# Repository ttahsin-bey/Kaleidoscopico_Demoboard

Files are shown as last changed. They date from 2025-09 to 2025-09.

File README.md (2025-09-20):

# Demoboard for LFT's Demo "Kaleidoscopico"

Demos always look better on real hardware. That's what everyone says.

That's why I designed this small circuit board for myself, so that I can run LFT's demo on real hardware instead of just watching it on YouTube. I didn't want to build his version on a stripboard, but preferred a clean solution with SMT components.

Rendering

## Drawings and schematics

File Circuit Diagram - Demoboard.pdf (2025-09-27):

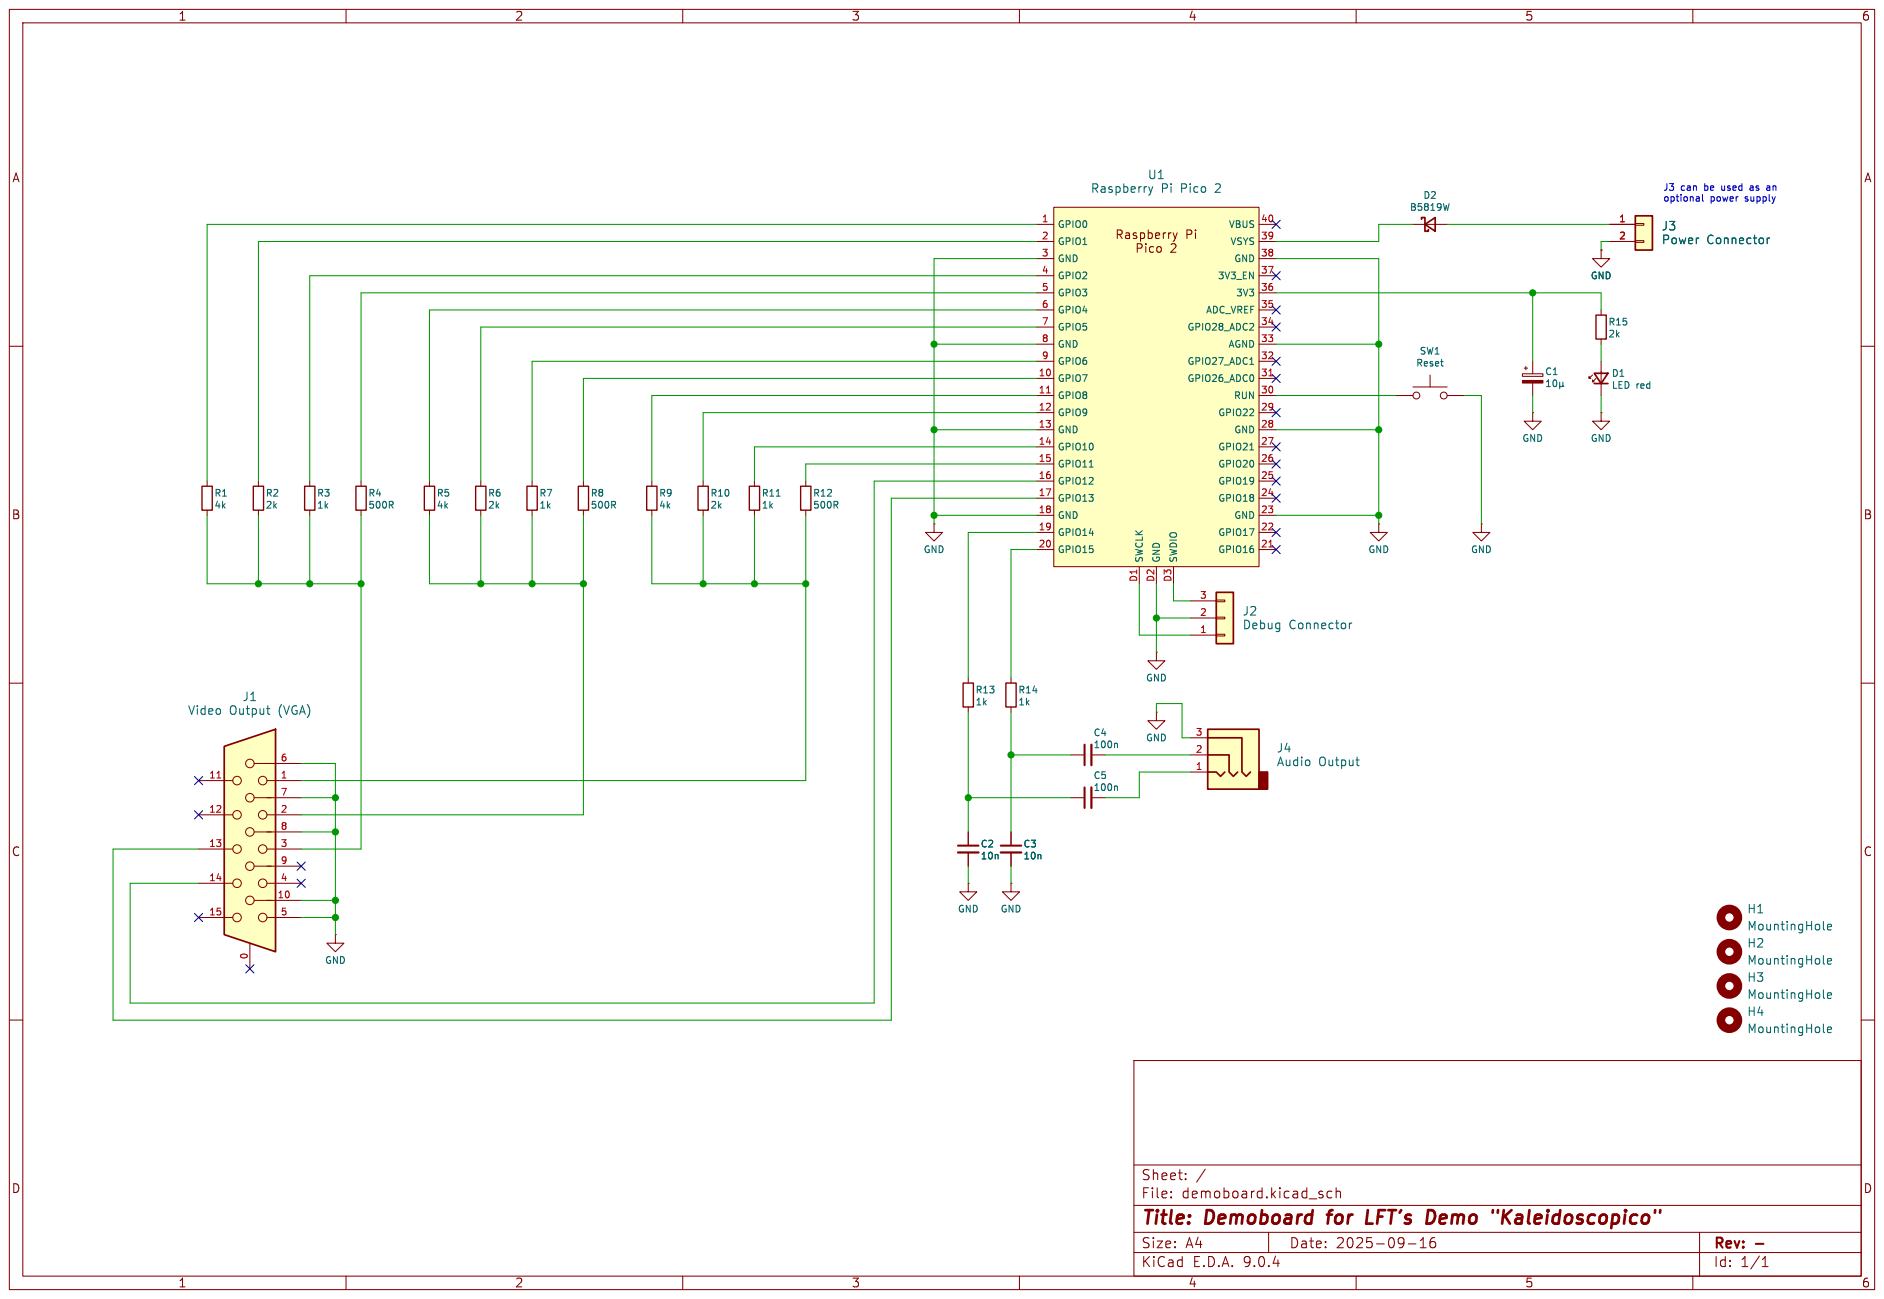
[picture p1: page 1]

J3 can be used as an

File: demoboard.kicad_sch Sheet: /
Id: 1/1 Title: Demoboard for LFT's Demo "Kaleidoscopico"

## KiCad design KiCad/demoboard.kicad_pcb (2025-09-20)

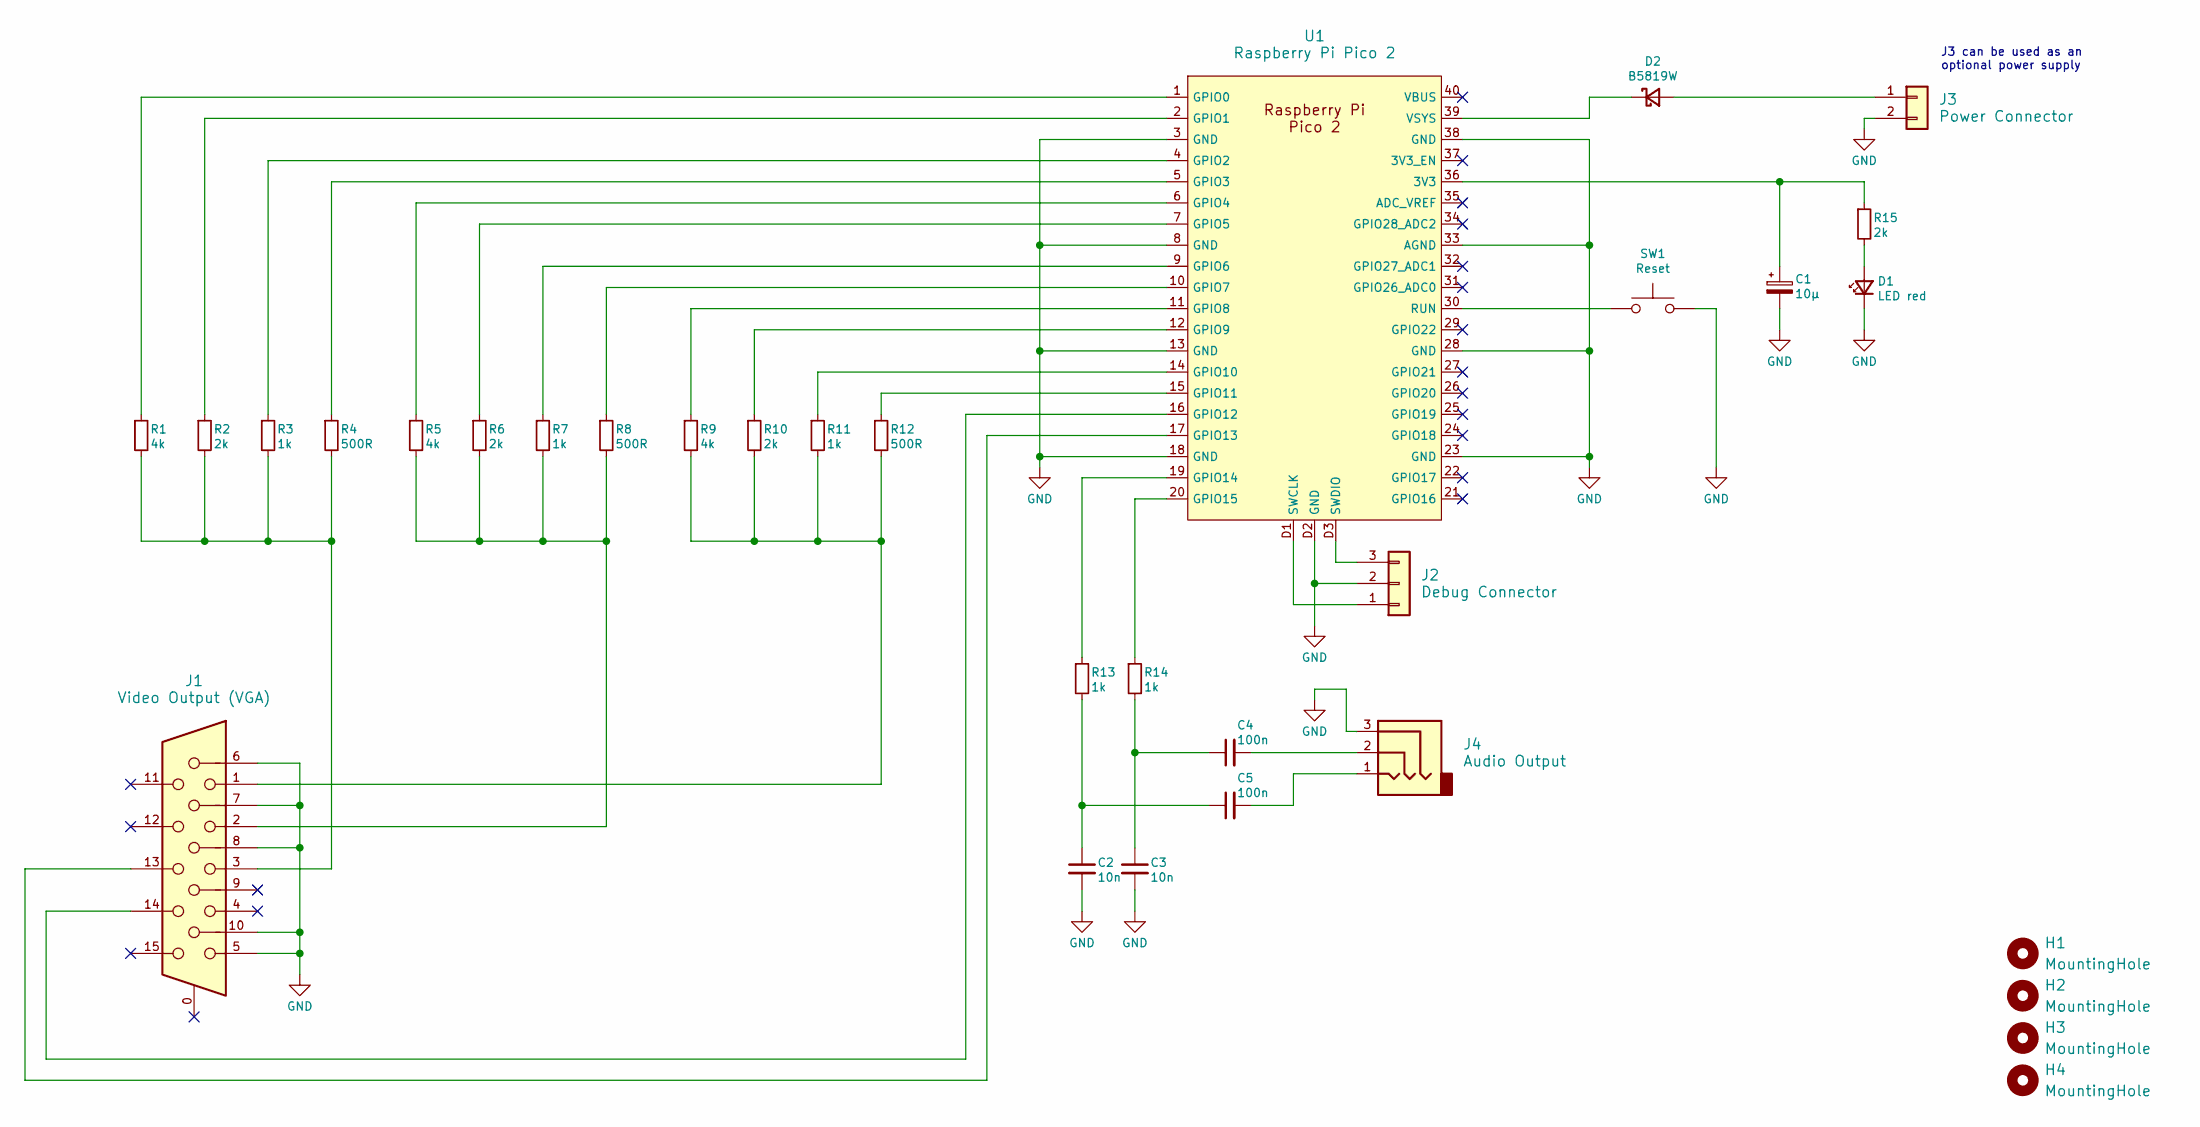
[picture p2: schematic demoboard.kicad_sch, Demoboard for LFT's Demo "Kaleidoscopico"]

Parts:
C1: 10µ; CP_Elec_4x5.4; LCSC C264230
C2, C3: 10n; C_0805_2012Metric; LCSC C1710
C4, C5: 100n; C_0805_2012Metric; LCSC C49678
D1: LED red; LED_0805_2012Metric; LCSC C84256
D2: B5819W; TTB_D_SOD-123; LCSC C8598
H1, H2, H3, H4: MountingHole; MountingHole_2.5mm
J1: Video Output (VGA); DSUB-15-HD_Socket_Horizontal_P2.29x2.54mm_EdgePinOffset8.35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; LCSC C711363
J2: Debug Connector; PinHeader_1x03_P2.54mm_Vertical; LCSC C42431836
J3: Power Connector; JST_PH_B2B-PH-K_1x02_P2.00mm_Vertical; LCSC C131337
J4: Audio Output; TTB_Audio; LCSC C711363
R1, R5, R9: 4k; R_0805_2012Metric; LCSC C2828855
R2, R6, R10, R15: 2k; R_0805_2012Metric; LCSC C218483
R3, R7, R11, R13, R14: 1k; R_0805_2012Metric; LCSC C218388
R4, R8, R12: 500R; R_0805_2012Metric; LCSC C2828857
SW1: Reset; TTB_PushbuttonSMD; LCSC C5340123
U1: Raspberry Pi Pico 2; RaspberryPi_Pico_SMD

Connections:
GND: C1.2, C2.2, C3.2, D1.1 (K), J1.5, J1.6, J1.7, J1.8, J1.10, J2.2, J3.2, J4.3, SW1.2, U1.3 (GND), U1.8 (GND), U1.13 (GND), U1.18 (GND), U1.23 (GND), U1.28 (GND), U1.33 (AGND), U1.38 (GND), U1.D2 (GND)
unnamed: C2.1, C5.1, R13.2
unnamed: C3.1, C4.1, R14.2
unnamed: C4.2, J4.2
unnamed: C5.2, J4.1
unnamed: D1.2 (A), R15.2
unnamed: D2.2 (A), J3.1
unnamed: D2.1 (K), U1.39 (VSYS)
unnamed: J1.1, R9.2, R10.2, R11.2, R12.2
unnamed: J1.2, R5.2, R6.2, R7.2, R8.2
unnamed: J1.3, R1.2, R2.2, R3.2, R4.2
unnamed: J2.1, U1.D1 (SWCLK)
unnamed: J2.3, U1.D3 (SWDIO)
unnamed: C1.1, R15.1, U1.36 (3V3)
unnamed: R1.1, U1.1 (GPIO0)
unnamed: R2.1, U1.2 (GPIO1)
unnamed: R3.1, U1.4 (GPIO2)
unnamed: R4.1, U1.5 (GPIO3)
unnamed: R5.1, U1.6 (GPIO4)
unnamed: R6.1, U1.7 (GPIO5)
unnamed: R7.1, U1.9 (GPIO6)
unnamed: R8.1, U1.10 (GPIO7)
unnamed: R9.1, U1.11 (GPIO8)
unnamed: R10.1, U1.12 (GPIO9)
unnamed: R11.1, U1.14 (GPIO10)
unnamed: R12.1, U1.15 (GPIO11)
unnamed: J1.14, U1.16 (GPIO12)
unnamed: J1.13, U1.17 (GPIO13)
unnamed: R13.1, U1.19 (GPIO14)
unnamed: R14.1, U1.20 (GPIO15)
unnamed: SW1.1, U1.30 (RUN)

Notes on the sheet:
J3 can be used as an optional power supply

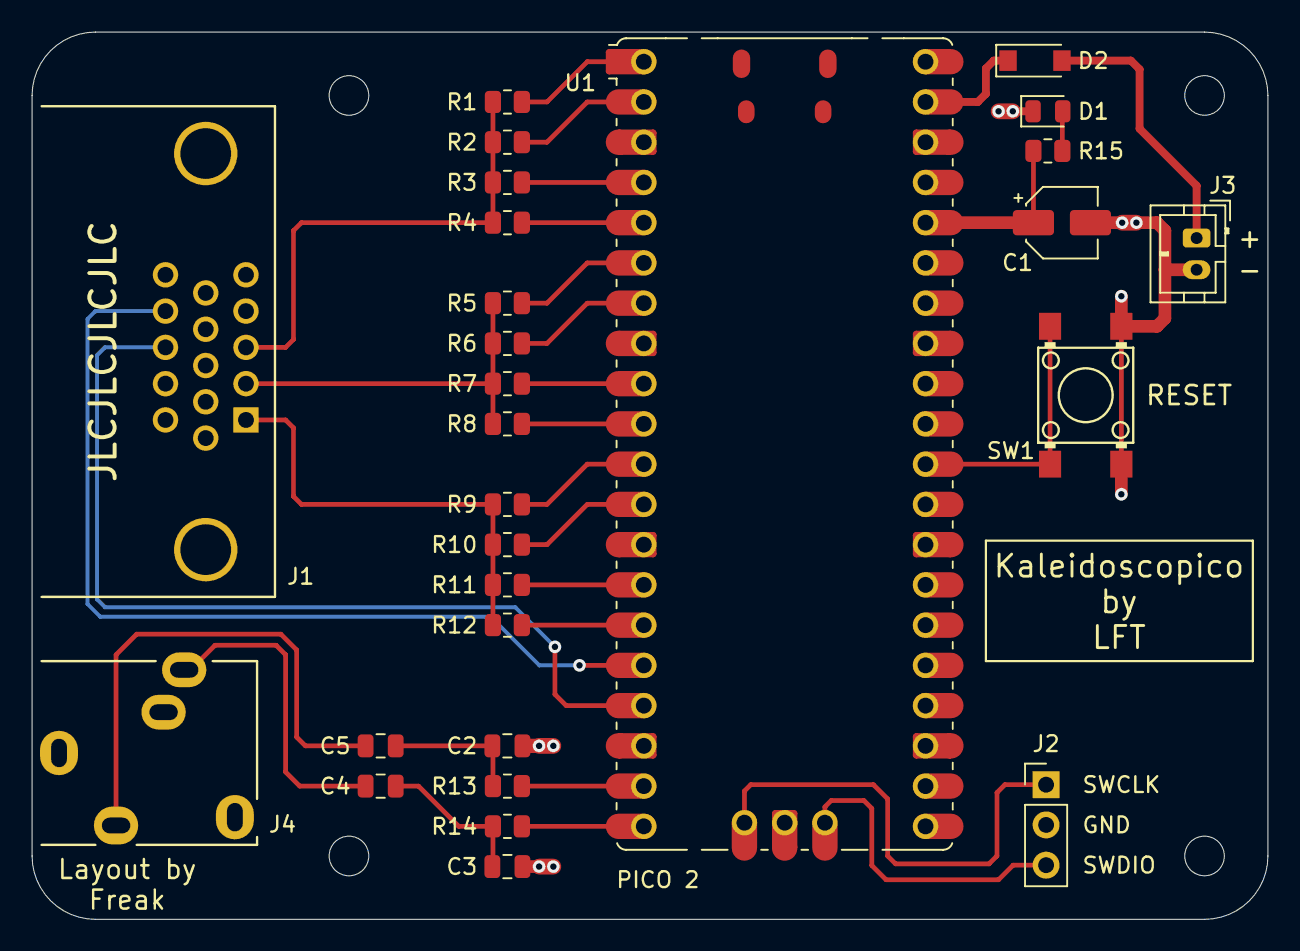
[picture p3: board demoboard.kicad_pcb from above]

Board: 2 copper layers, 78.0 x 56.0 mm, 32 parts (0 on the bottom side), 31 nets.

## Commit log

2025-09-20 Production files added
    [demoboard-B_Cu.gbr, demoboard-B_Mask.gbr, demoboard-B_Silkscreen.gbr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]
2025-09-27 Circuit Diagram added
